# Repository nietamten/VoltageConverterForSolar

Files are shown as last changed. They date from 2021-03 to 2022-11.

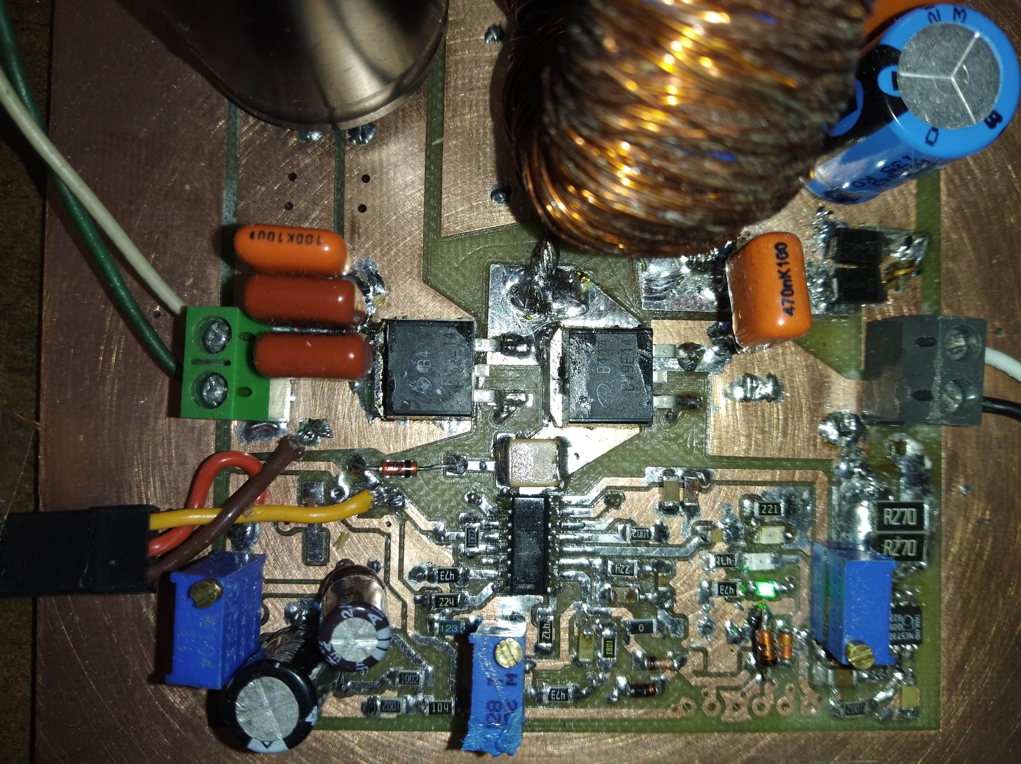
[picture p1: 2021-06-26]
pictures/v2opt.jpg

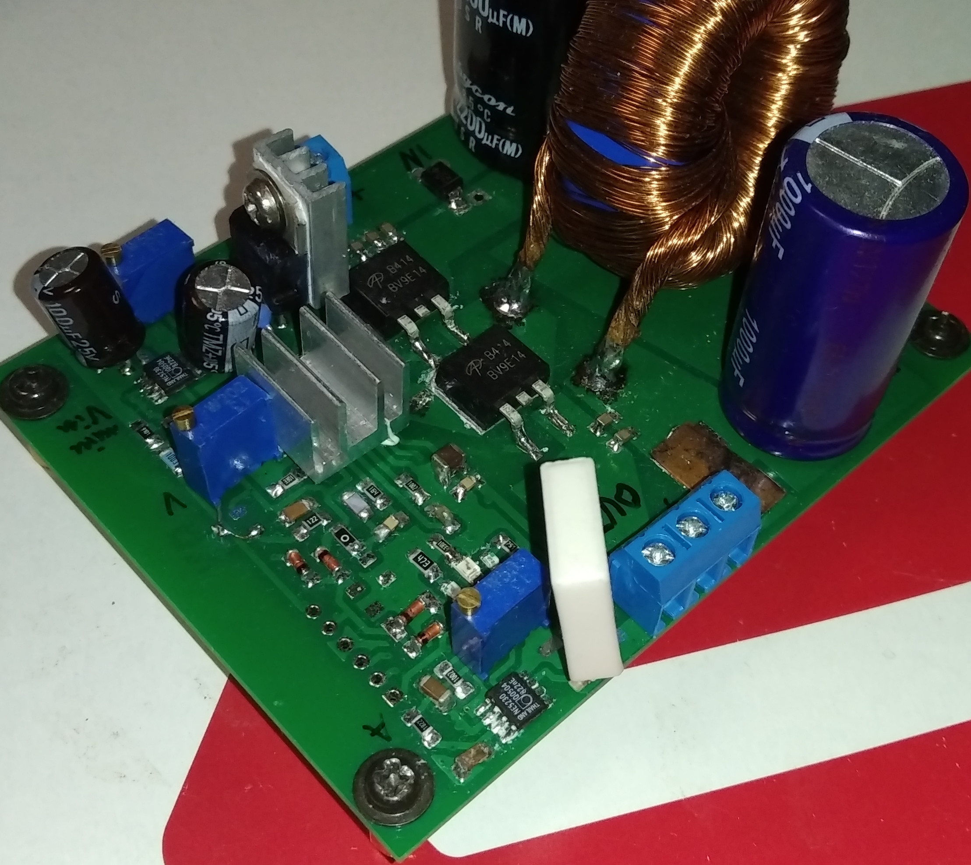
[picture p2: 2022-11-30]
pictures/v3.jpg

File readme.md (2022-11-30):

Kicad project of NCP1034 based buck converter with features useful for solar panels and batteries.

After adjusting compensation network with "Design Spreadsheet for NCP1034" seems to be stable  
If it's not, see troubleshooting section.

There is separate output anode with current limit. It can be used simultaneously with that not limited.
For example battery can be charged with limiting (to not damage it by overcurrent) and some device can use non-limited anode to not distgurb charging.
It is not working ideally (limited output can limit that not limited) but can be helpfull.

Minimum input voltage limit can increase output power by keeping solar panels near maximum power point.
It can be regulated by applying load higher than solar panels power (or when panel are no well illuminated, but not too low illuminated because looses on BD911 regulator becomes dominant and then input voltages lower than at power point gives more power on output) and measuring output power.
Limiting screw should stay in position where power is highest.

NCP1034 have max 80% PWM duty cycle, all power can not pass throw.
Output diodes (D6 and D9) can be replaced with wire, but then converter allows power to flow in reverse direction. When there is no input volatge and on output is battery, battery can charge input capacitors and power on converter and cause losses. 

Assembly notices:
- read NCP1034 datasheet and use xls "design worksheet"
- BD911 gives off a lot of heat, don't ommit radiator, it will be damaged on 15V supply overload
For testing, when short circuits are possible, raplace BD911 based regulator with some other, more failproof
for example LM5008 based converter. Using LM5008 also significantly reduces heat of whole device on light loads.
- do not ommit 3x100nF capacitors on imput, it can cause instability
- current sensing resistor (R13, R16) limits maximum current, use lower resistance when more current is needed to not burn it
- RT pin resistor (R7) was tested between 22k and 47k (90-180kHz), lower resistance (higher frequency) makes more heat on NCP1034, BD911 and AOB414 but seems to improve stability
(I have oversized inductor). Setting too high frequency can very fast cause overheat and damage to NCP1034.
- Touching working converter parts near NCP1034 (for example to check heating) can easily cause damage of NCP1034 and AOB414. Especially overcurrent and soft start circuits.
- do not mount parts without values, for exaple C21

Troubleshooting:
- converter is oscillating fast (there is output power)
  - increase input capacity
  - add low ESR capacitors on input, for example ceramic
  - change frequency (R7)
- converter is oscillating slower (a little or no power on output)
  - decrease output capacity to prevent over current
  - increase current limit (decrease R11), 5k seems to be safe
  - decrease output volage
- converter is oscillating when minimum voltage limit is working
  - try increase C19 or C18
- converter is oscillating when current limiter is working
  - try increase C16 or experiment with C22
- devices near converter stops working (usb mouse)
  - use ferrite filters on input and output
 
Testing  
Device was tested with 4x parallel 75W 91VOC 67VMP solar panels on long wires.
The load was little 24V 300W water heater.
The heater was left on the whole sunny day in room temperature and stay not damagd.
Voltage on output was for some time about 27V so I suspect that it was more than 300W.
AOB414, BD911 and NCP1034 was very hot but below 100C. I'm not sure it can survive that load in higher ambient temperature.
With lighter loads (I'm guessing about 200W) BD911 is hottest. With LM5008 whole converter is only a little warm.

There is not completed automatic maximum power point tracking extension board with some measurments on UART 

V2 tagged version is better for self-made PCB's but have mistake - no resistor at output of  max input voltage limiting opamp.
V3 tagged verion is for PCB's with metalized holes, radiator for transistors can be on second PCB side.

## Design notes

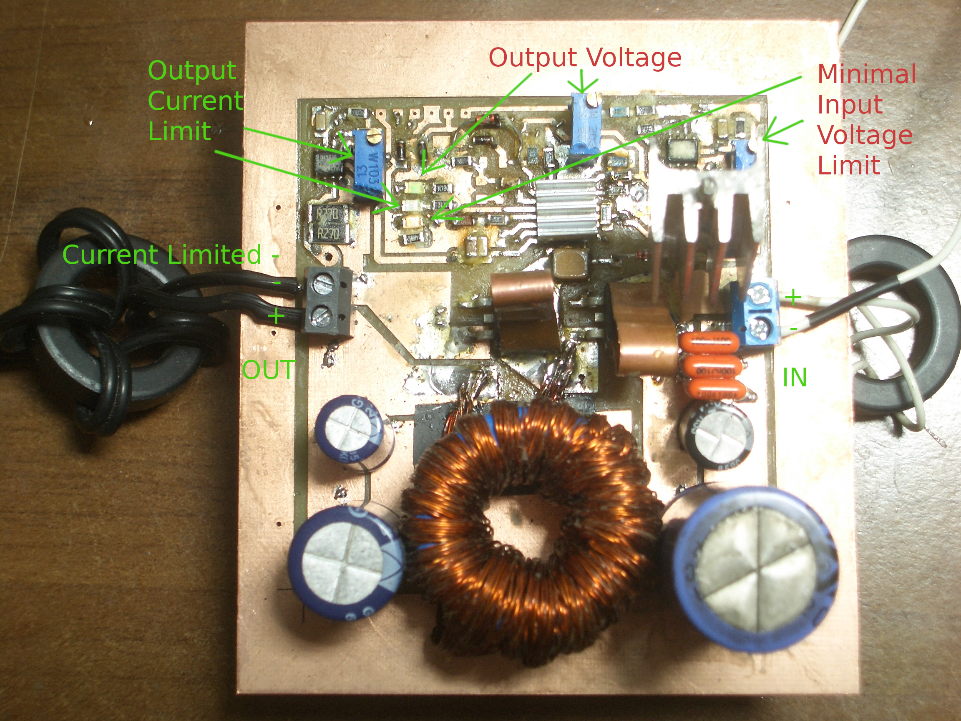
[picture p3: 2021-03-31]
pictures/desc.jpg

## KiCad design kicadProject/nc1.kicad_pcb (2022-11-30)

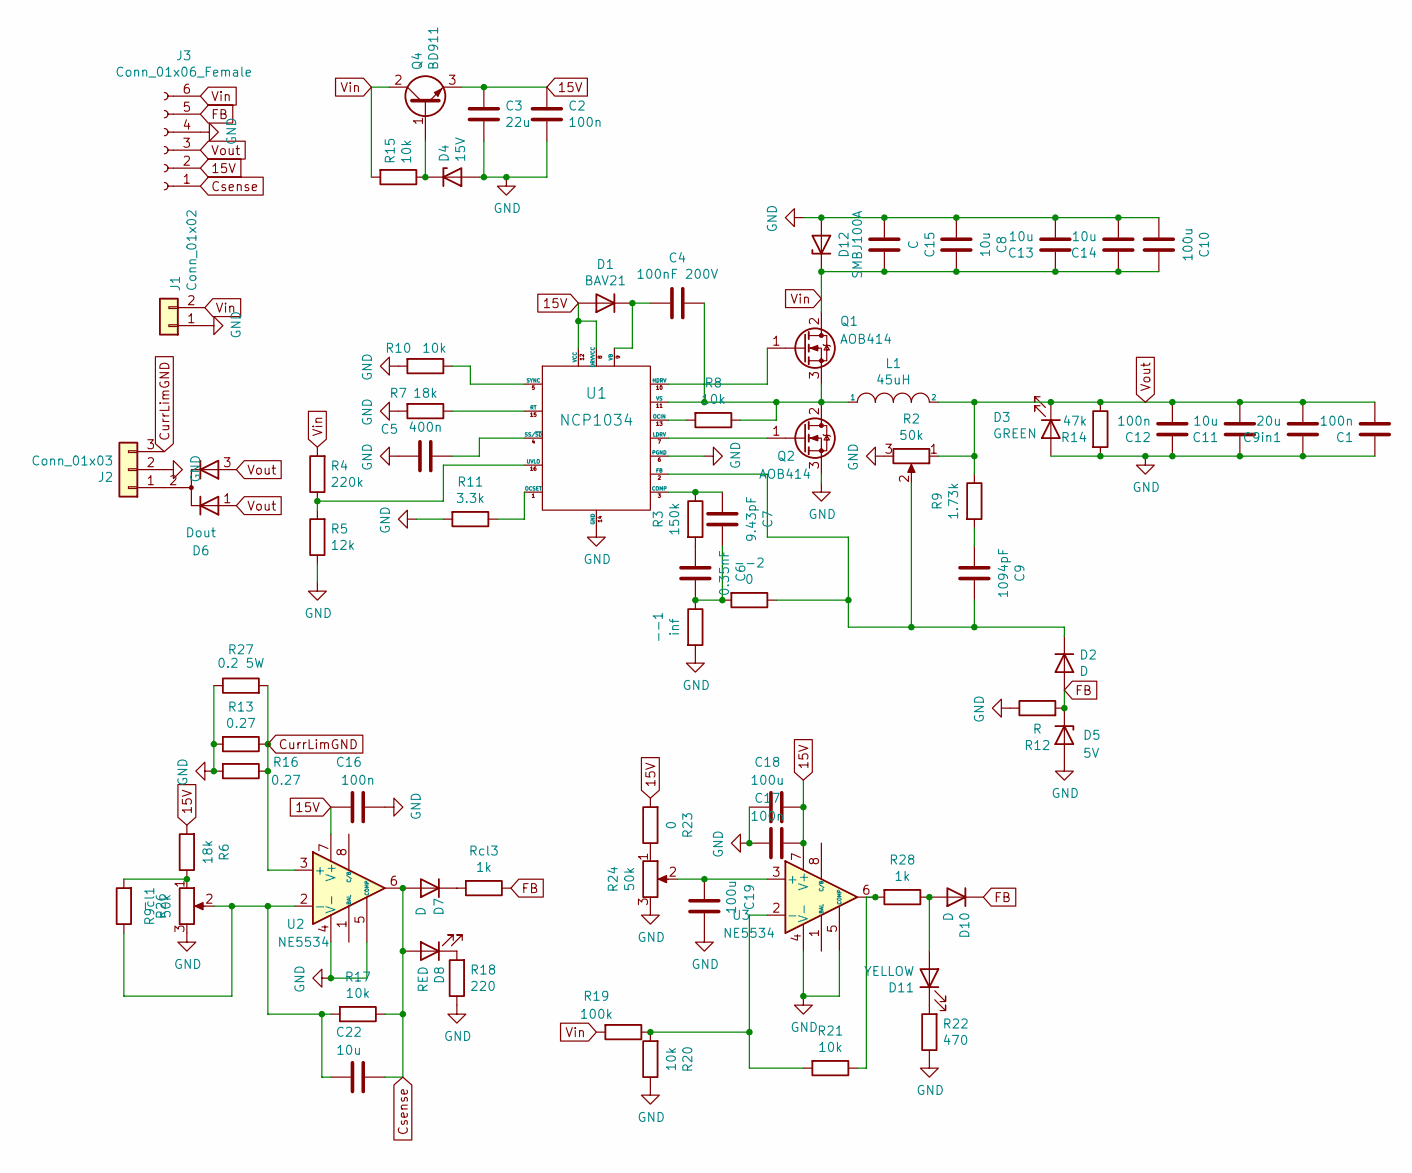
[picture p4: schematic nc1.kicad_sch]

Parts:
--1: inf; R_1206_3216Metric_Pad1.30x1.75mm_HandSolder
--2: 0; R_1206_3216Metric_Pad1.30x1.75mm_HandSolder
C1: 100n; CP_Radial_D18.0mm_P7.50mm
C2: 100n; C_1206_3216Metric
C3: 22u; C_1206_3216Metric
C4: 100nF 200V; C_2220_5650Metric
C5: 400n; C_1206_3216Metric_Pad1.42x1.75mm_HandSolder
C6: 0.35nF; C_1206_3216Metric_Pad1.42x1.75mm_HandSolder
C7: 9.43pF; C_1206_3216Metric_Pad1.42x1.75mm_HandSolder
C8: 10u; C_Rect_L7.0mm_W2.5mm_P5.00mm
C9: 1094pF; C_1206_3216Metric_Pad1.33x1.80mm_HandSolder
C9in1: 20u; C_Rect_L7.0mm_W2.5mm_P5.00mm
C10: 100u; C_Rect_L7.0mm_W2.5mm_P5.00mm
C11, C13, C14: 10u; CP_Radial_D16.0mm_P7.50mm
C12: 100n; C_Rect_L7.0mm_W2.5mm_P5.00mm
C15: C; C_Rect_L7.0mm_W2.5mm_P5.00mm
C16, C17: 100n; C_1206_3216Metric_Pad1.33x1.80mm_HandSolder
C18, C19: 100u; CP_Radial_D5.0mm_P2.50mm
C22: 10u; C_1206_3216Metric_Pad1.33x1.80mm_HandSolder
D1: BAV21; D_A-405_P10.16mm_Horizontal
D2, D7, D10: D; D_MiniMELF
D3: GREEN; LED_0805_2012Metric_Pad1.15x1.40mm_HandSolder
D4: 15V; D_MELF
D5: 5V; D_MELF
D6: Dout; TO-220-3_Vertical
D8: RED; LED_0805_2012Metric_Pad1.15x1.40mm_HandSolder
D11: YELLOW; LED_0805_2012Metric_Pad1.15x1.40mm_HandSolder
D12: SMBJ100A; D_SMB
J1: Conn_01x02; TerminalBlock_bornier-2_P5.08mm
J2: Conn_01x03; TerminalBlock_bornier-3_P5.08mm
J3: Conn_01x06_Female; PinHeader_1x06_P2.54mm_Vertical
L1: 45uH; L_Axial_L9.5mm_D4.0mm_P15.24mm_Horizontal_Fastron_SMCC
Q1, Q2: AOB414; TO-263-2
Q4: BD911; TO-220-3_Vertical
R2, R9cl1, R24: 50k; Potentiometer_Bourns_3296W_Vertical
R3: 150k; R_1206_3216Metric_Pad1.30x1.75mm_HandSolder
R4: 220k; R_1206_3216Metric_Pad1.30x1.75mm_HandSolder
R5: 12k; R_1206_3216Metric_Pad1.30x1.75mm_HandSolder
R6, R7: 18k; R_1206_3216Metric_Pad1.30x1.75mm_HandSolder
R8, R10, R17, R20, R21: 10k; R_1206_3216Metric_Pad1.30x1.75mm_HandSolder
R9: 1.73k; R_1206_3216Metric_Pad1.30x1.75mm_HandSolder
R11: 3.3k; R_1206_3216Metric_Pad1.30x1.75mm_HandSolder
R12: R; R_1206_3216Metric_Pad1.30x1.75mm_HandSolder
R13, R16: 0.27; R_2010_5025Metric_Pad1.40x2.65mm_HandSolder
R14: 47k; R_1206_3216Metric_Pad1.30x1.75mm_HandSolder
R15: 10k; R_Axial_DIN0207_L6.3mm_D2.5mm_P10.16mm_Horizontal
R18: 220; R_1206_3216Metric_Pad1.30x1.75mm_HandSolder
R19: 100k; R_1206_3216Metric_Pad1.30x1.75mm_HandSolder
R22: 470; R_1206_3216Metric_Pad1.30x1.75mm_HandSolder
R23: 0; R_1206_3216Metric_Pad1.30x1.75mm_HandSolder
R26: -; R_1206_3216Metric_Pad1.30x1.75mm_HandSolder
R27: 0.2 5W; R_Radial_Power_L16.1mm_W9.0mm_P7.37mm
R28: 1k; R_1206_3216Metric_Pad1.30x1.75mm_HandSolder
Rcl3: 1k; R_0805_2012Metric
U1: NCP1034; SOIC-16_3.9x9.9mm_P1.27mm
U2, U3: NE5534; SOIC-8_3.9x4.9mm_P1.27mm

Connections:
15V: C2.1, C3.1, C16.1, C17.2, C18.2, D1.2 (A), J3.2, Q4.3 (E), R6.2, R23.2, U1.8 (DRVVCC), U1.12 (VCC), U2.7 (V+), U3.7 (V+)
Csense: C22.2, D7.2 (A), D8.2 (A), J3.1, R17.1, U2.6
CurrLimGND: J2.3, R13.1, R16.1, R27.2, U2.3 (+)
FB: D2.2 (A), D5.1 (K), D10.1 (K), J3.5, R12.2, Rcl3.1
GND: --1.2, C1.2, C2.2, C3.2, C5.2, C8.2, C9in1.2, C10.2, C11.2, C12.2, C13.1, C14.1, C15.2, C16.2, C17.1, C18.1, C19.2, D3.2 (A), D4.2 (A), D5.2 (A), D12.2 (A), J1.1, J2.2, J3.4, Q2.3 (S), R2.3, R5.1, R7.2, R9cl1.3, R10.2, R11.2, R12.1, R13.2, R14.2, R16.2, R18.1, R20.1, R22.1, R24.3, R27.1, U1.6 (PGND), U1.14 (GND), U2.4 (V-), U2.5 (COMP), U3.4 (V-), U3.5 (COMP)
unnamed: --1.1, --2.2, C6.1, C7.1
unnamed: --2.1, C9.1, D2.1 (K), R2.2, U1.2 (FB)
unnamed: C4.1, L1.1, Q1.3 (S), Q2.2 (D), R8.1, U1.11 (VS)
unnamed: C4.2, D1.1 (K), U1.9 (VB)
unnamed: C5.1, U1.4 (SS/~SD)
unnamed: C6.2, R3.2
unnamed: C7.2, R3.1, U1.3 (COMP)
unnamed: C9.2, R9.2
unnamed: C19.1, R24.2, U3.3 (+)
unnamed: C22.1, R9cl1.2, R17.2, R26.1, U2.2 (-)
unnamed: D4.1 (K), Q4.1 (B), R15.1
unnamed: D7.1 (K), Rcl3.2
unnamed: D8.1 (K), R18.2
unnamed: D10.2 (A), D11.2 (A), R28.1
unnamed: D6.2 (A), J2.1
unnamed: Q1.1 (G), U1.10 (HDRV)
unnamed: Q2.1 (G), U1.7 (LDRV)
unnamed: R4.1, R5.2, U1.16 (UVLO)
unnamed: R7.1, U1.15 (RT)
unnamed: R8.2, U1.13 (OCIN)
unnamed: R11.1, U1.1 (OCSET)
unnamed: R19.1, R20.2, R21.2, U3.2 (-)
unnamed: R21.1, R28.2, U3.6
unnamed: D11.1 (K), R22.2
unnamed: R23.1, R24.1
unnamed: R6.1, R9cl1.1, R26.2
unnamed: R10.1, U1.5 (SYNC)
Vin: C8.1, C10.1, C13.2, C14.2, C15.1, D12.1 (K), J1.2, J3.6, Q1.2 (D), Q4.2 (C), R4.2, R15.2, R19.2
Vout: C1.1, C9in1.1, C11.1, C12.1, D3.1 (K), D6.1 (K), D6.3 (K), J3.3, L1.2, R2.1, R9.1, R14.1

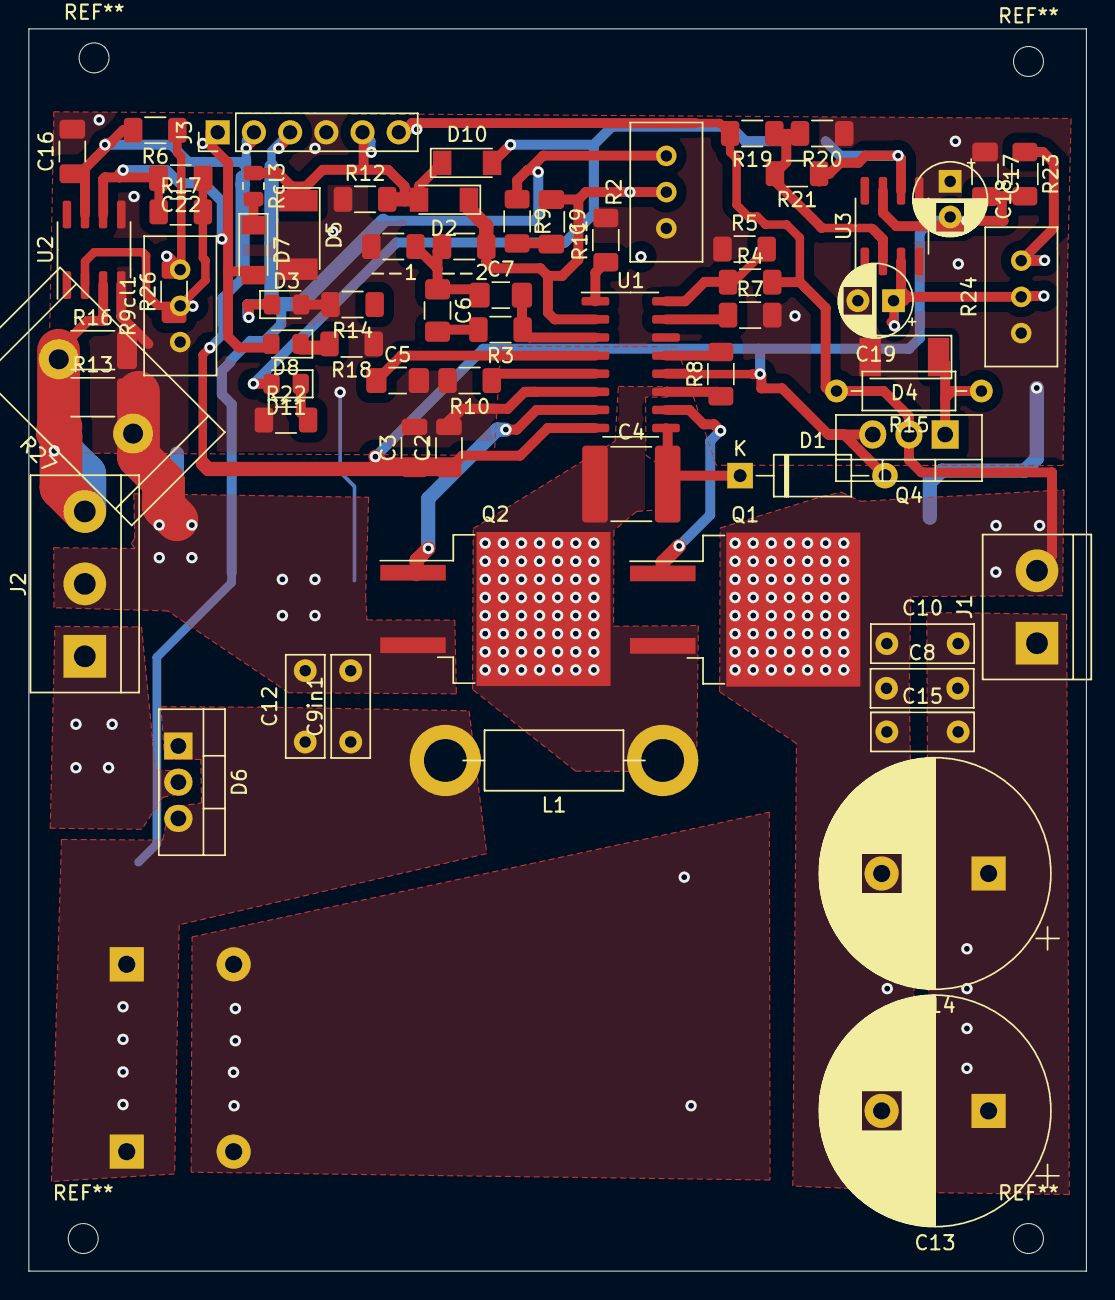
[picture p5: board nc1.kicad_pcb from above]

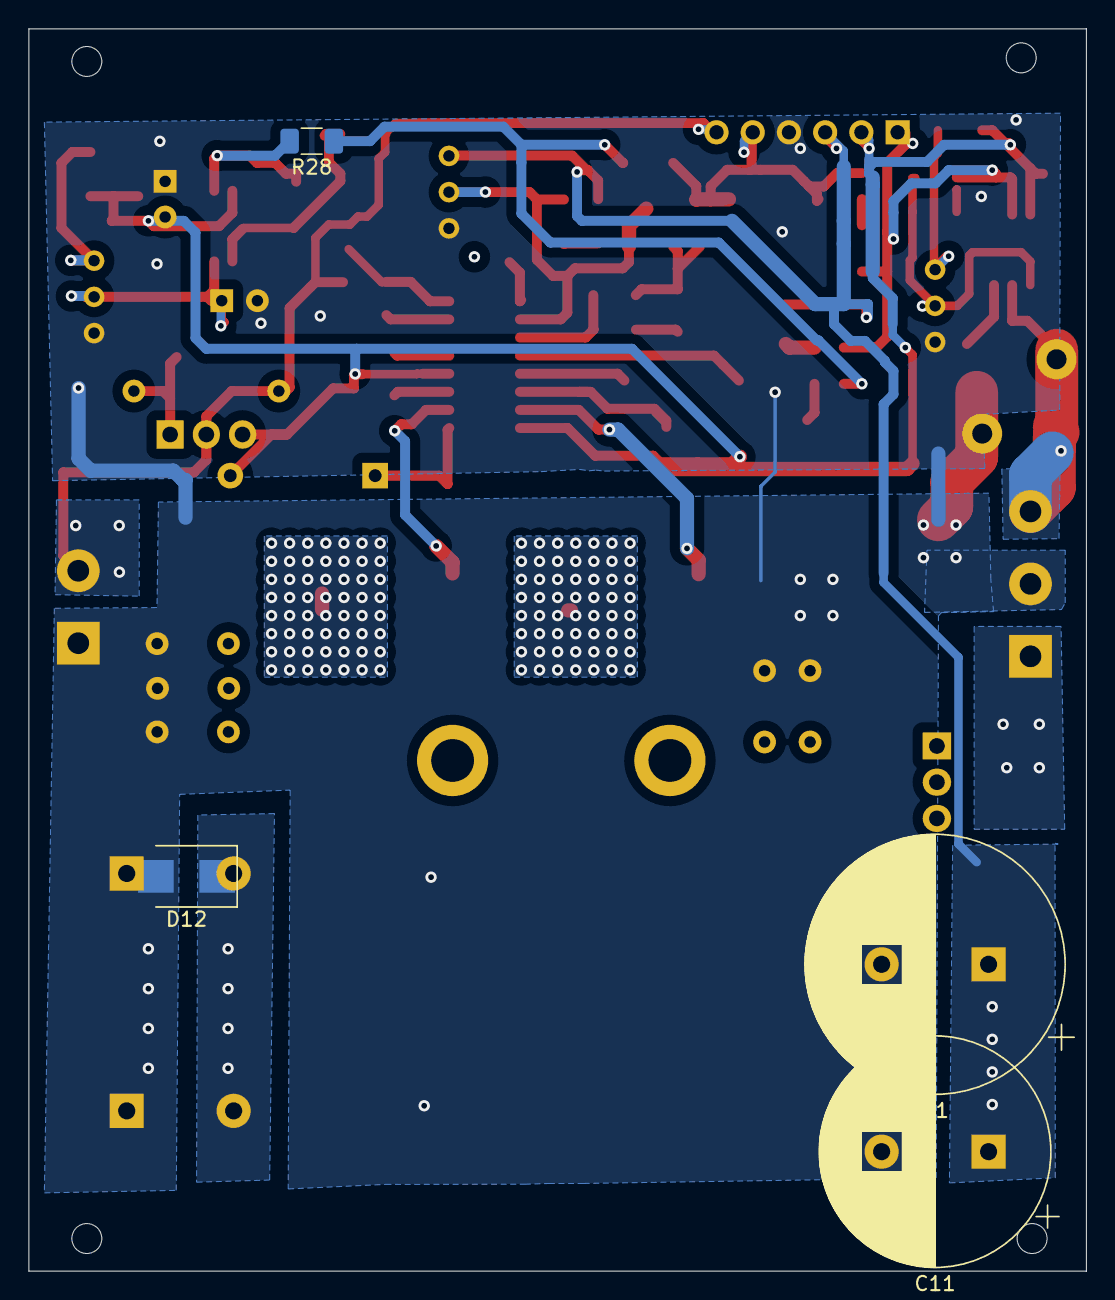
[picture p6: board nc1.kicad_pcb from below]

Board: 2 copper layers, 74.2 x 87.1 mm, 72 parts (4 on the bottom side), 34 nets.

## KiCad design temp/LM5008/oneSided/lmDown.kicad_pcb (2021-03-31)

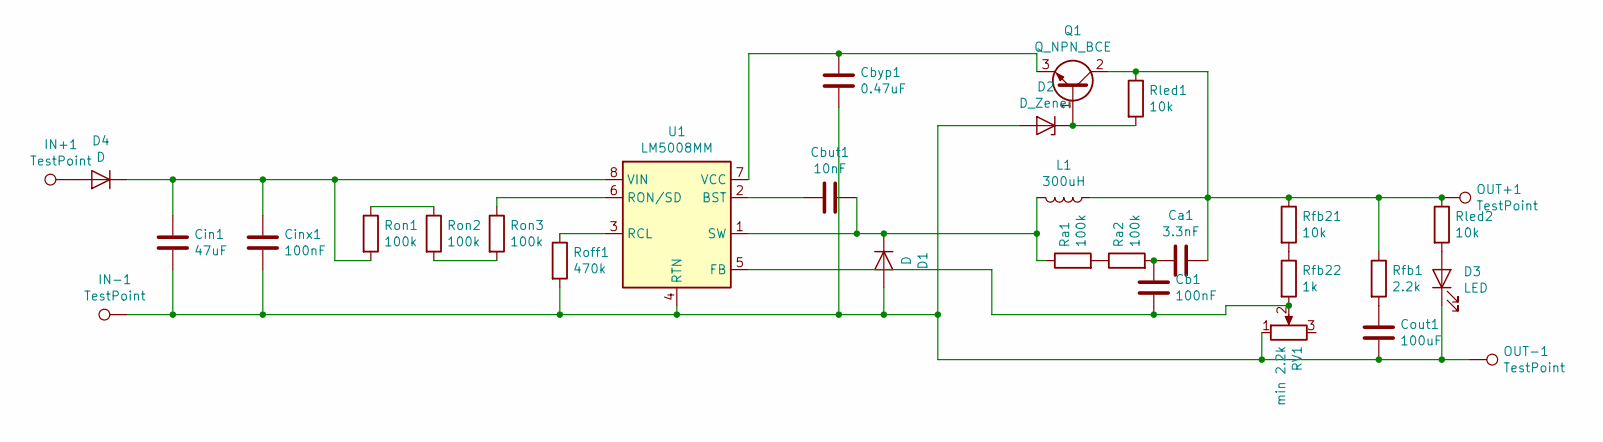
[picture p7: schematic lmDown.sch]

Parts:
Ca1: 3.3nF; C_1206_3216Metric_Pad1.42x1.75mm_HandSolder
Cb1: 100nF; C_1206_3216Metric_Pad1.42x1.75mm_HandSolder
Cbut1: 10nF; C_Disc_D7.5mm_W5.0mm_P5.00mm
Cbyp1: 0.47uF; C_0805_2012Metric_Pad1.15x1.40mm_HandSolder
Cin1: 47uF; CP_Radial_D8.0mm_P3.80mm
Cinx1: 100nF; C_Rect_L7.2mm_W3.5mm_P5.00mm_FKS2_FKP2_MKS2_MKP2
Cout1: 100uF; CP_Radial_D10.0mm_P5.00mm
D1: D; D_DO-15_P10.16mm_Horizontal
D2: D_Zener; D_1206_3216Metric
D3: LED; LED_0805_2012Metric
D4: D; D_A-405_P10.16mm_Horizontal
IN+1: TestPoint; TestPoint_Loop_D2.50mm_Drill1.85mm
IN-1: TestPoint; TestPoint_Loop_D2.50mm_Drill1.85mm
L1: 300uH; L_Radial_D10.0mm_P5.00mm_Fastron_07P
OUT+1: TestPoint; TestPoint_Loop_D2.50mm_Drill1.85mm
OUT-1: TestPoint; TestPoint_Loop_D2.50mm_Drill1.85mm
Q1: Q_NPN_BCE; TO-92L_Inline_Wide
RV1: min 2.2k; Potentiometer_Runtron_RM-065_Vertical
Ra1, Ra2: 100k; R_1206_3216Metric_Pad1.42x1.75mm_HandSolder
Rfb1: 2.2k; R_1206_3216Metric_Pad1.42x1.75mm_HandSolder
Rfb21: 10k; R_1206_3216Metric_Pad1.42x1.75mm_HandSolder
Rfb22: 1k; R_1206_3216Metric_Pad1.42x1.75mm_HandSolder
Rled1, Rled2: 10k; R_1206_3216Metric_Pad1.42x1.75mm_HandSolder
Roff1: 470k; R_1206_3216Metric_Pad1.42x1.75mm_HandSolder
Ron1, Ron2, Ron3: 100k; R_1206_3216Metric_Pad1.42x1.75mm_HandSolder
U1: LM5008MM; MSOP-8_3x3mm_P0.65mm

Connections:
unnamed: Ca1.1, L1.1, OUT+1.1, Q1.2 (C), Rfb1.1, Rfb21.1, Rled1.1, Rled2.1
unnamed: Ca1.2, Cb1.1, Ra2.2
unnamed: Cb1.2, RV1.2, Rfb22.2, U1.5 (FB)
unnamed: Cbut1.1, D1.1 (K), L1.2, Ra1.1, U1.1 (SW)
unnamed: Cbut1.2, U1.2 (BST)
unnamed: Cbyp1.1, Q1.3 (E), U1.7 (VCC)
unnamed: Cbyp1.2, Cin1.2, Cinx1.2, Cout1.2, D1.2 (A), D2.2 (A), D3.1 (K), IN-1.1, OUT-1.1, RV1.1, Roff1.2, U1.4 (RTN)
unnamed: Cin1.1, Cinx1.1, D4.1 (K), Ron1.2, U1.8 (VIN)
unnamed: Cout1.1, Rfb1.2
unnamed: D2.1 (K), Q1.1 (B), Rled1.2
unnamed: D3.2 (A), Rled2.2
unnamed: D4.2 (A), IN+1.1
unnamed: Ra1.2, Ra2.1
unnamed: Rfb21.2, Rfb22.1
unnamed: Roff1.1, U1.3 (RCL)
unnamed 16: Ron1.1, Ron2.1; also elsewhere on the board
unnamed 17: Ron2.2, Ron3.2; also elsewhere on the board
unnamed: Ron3.1, U1.6 (RON/SD)

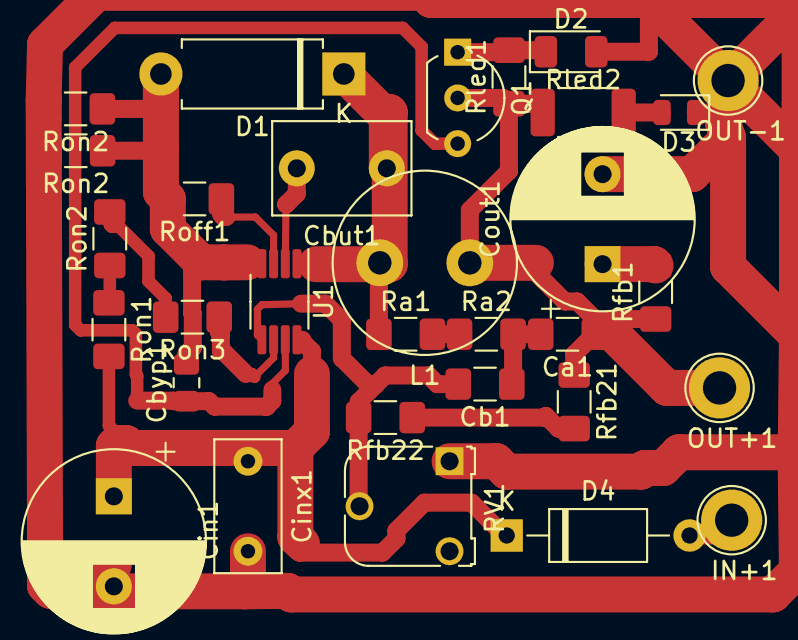
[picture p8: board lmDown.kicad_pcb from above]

Board: 2 copper layers, 31 parts (0 on the bottom side), 18 nets.

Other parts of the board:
Ron2#2, Ron2#3: 100k; R_1206_3216Metric_Pad1.42x1.75mm_HandSolder

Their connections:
unnamed 16: Ron2#2.1, Ron2#3.1; also elsewhere on the board
unnamed 17: Ron2#2.2, Ron2#3.2; also elsewhere on the board

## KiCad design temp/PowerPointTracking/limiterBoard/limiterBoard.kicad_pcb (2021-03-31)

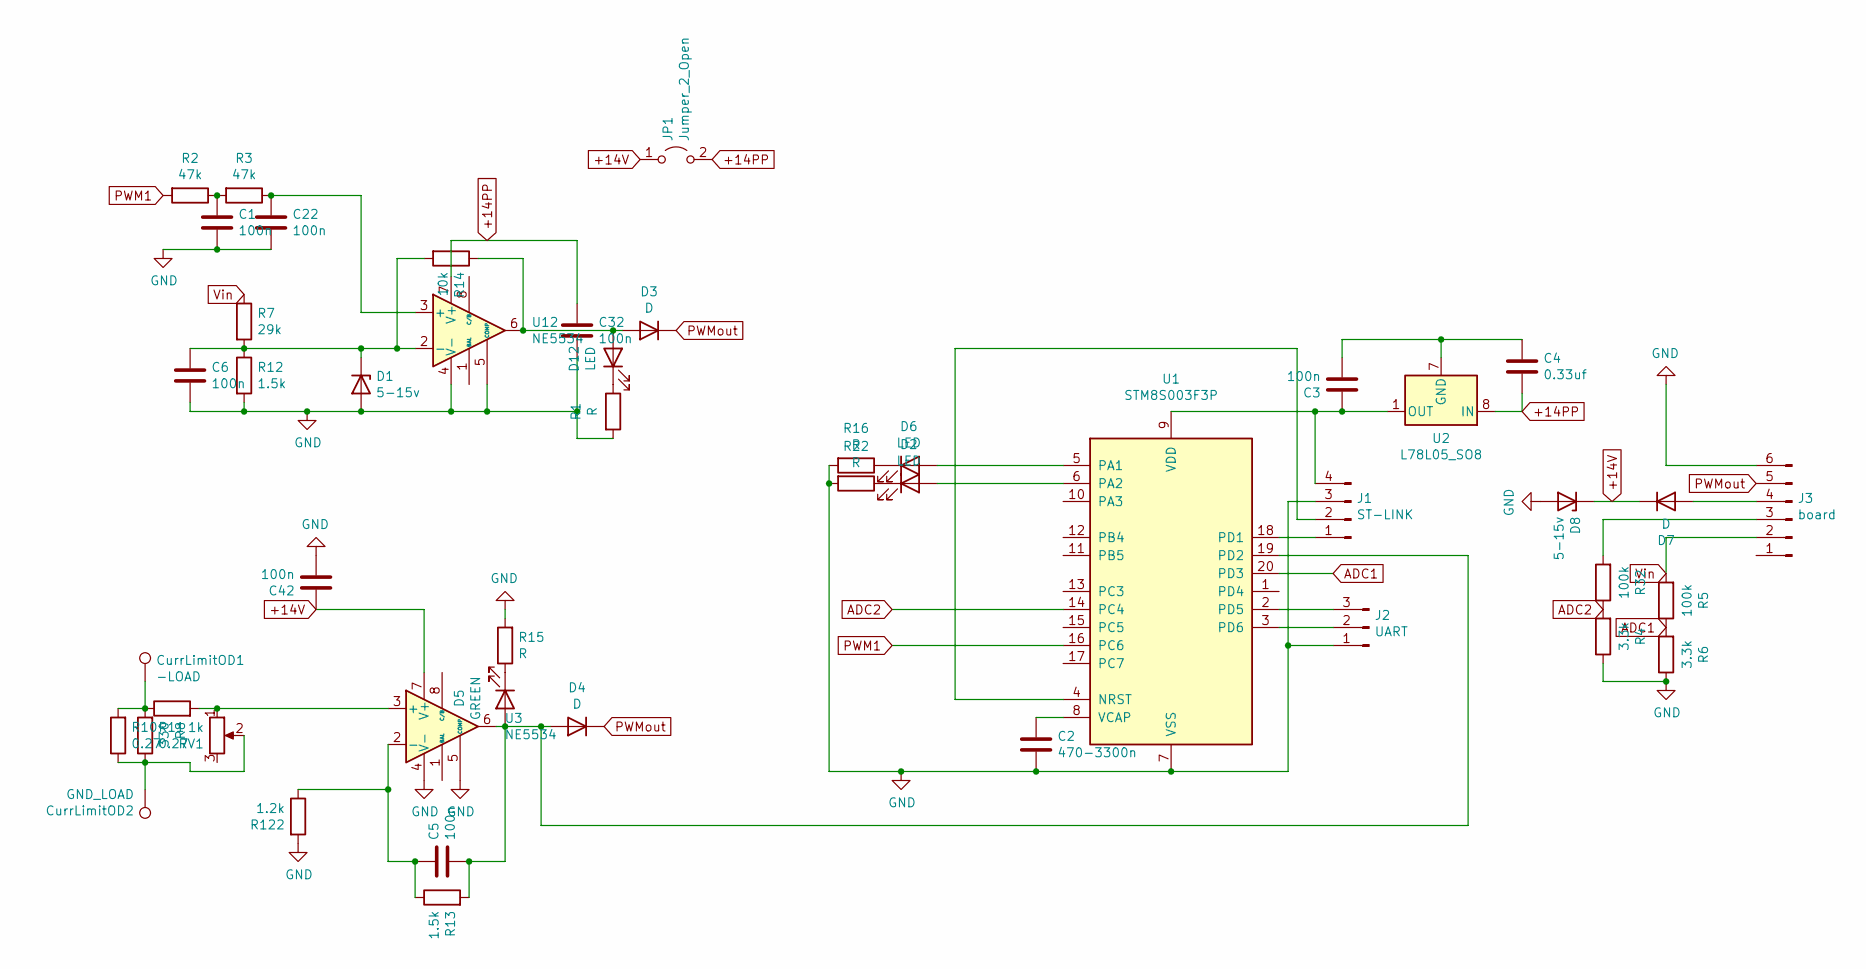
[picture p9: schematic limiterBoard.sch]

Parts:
C1, C3, C5, C6, C22, C32, C42: 100n; C_1206_3216Metric
C2: 470-3300n; C_1206_3216Metric
C4: 0.33uf; C_1206_3216Metric
CurrLimitOD1: -LOAD; SolderWire-0.1sqmm_1x01_D0.4mm_OD1mm
CurrLimitOD2: GND_LOAD; SolderWire-0.1sqmm_1x01_D0.4mm_OD1mm
D1, D8: 5-15v; D_MiniMELF
D2, D6, D12: LED; LED_1206_3216Metric_Pad1.42x1.75mm_HandSolder
D3, D4, D7: D; D_1210_3225Metric
D5: GREEN; LED_1206_3216Metric_Pad1.42x1.75mm_HandSolder
J1: ST-LINK; PinHeader_1x04_P2.54mm_Horizontal
J2: UART; PinHeader_1x03_P2.54mm_Horizontal
J3: board; PinHeader_1x06_P2.54mm_Horizontal
JP1: Jumper_2_Open; PinHeader_1x02_P2.54mm_Vertical
R1, R16, R22: R; R_1206_3216Metric
R2, R3: 47k; R_1206_3216Metric_Pad1.30x1.75mm_HandSolder
R4, R6: 3.3k; R_1206_3216Metric
R5, R32: 100k; R_1206_3216Metric
R7: 29k; R_1206_3216Metric_Pad1.30x1.75mm_HandSolder
R8: 330; R_1206_3216Metric_Pad1.30x1.75mm_HandSolder
R10, R11: 0.27; R_2512_6332Metric
R12, R13: 1.5k; R_1206_3216Metric_Pad1.30x1.75mm_HandSolder
R14: 10k; R_1206_3216Metric_Pad1.30x1.75mm_HandSolder
R15: R; R_1206_3216Metric_Pad1.30x1.75mm_HandSolder
R122: 1.2k; R_1206_3216Metric_Pad1.30x1.75mm_HandSolder
RV1: 1k; Potentiometer_Bourns_3269W_Vertical
U1: STM8S003F3P; TSSOP-20_4.4x6.5mm_P0.65mm
U2: L78L05_SO8; SOIC-8_3.9x4.9mm_P1.27mm
U3, U12: NE5534; SOIC-8_3.9x4.9mm_P1.27mm

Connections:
+14PP: C4.2, C32.1, JP1.2 (B), U2.8 (IN), U12.7 (V+)
+14V: C42.1, D7.1 (K), D8.1 (K), JP1.1 (A), U3.7 (V+)
ADC1: R5.1, R6.2, U1.20 (PD3)
ADC2: R4.2, R32.1, U1.14 (PC4)
GND: C1.2, C2.2, C6.2, C22.2, C32.2, C42.2, D1.2 (A), D8.2 (A), J1.3, J2.1, J3.6, R1.2, R4.1, R6.1, R12.2, R15.2, R16.2, R22.2, R122.2, U1.7 (VSS), U3.4 (V-), U3.5 (COMP), U12.4 (V-), U12.5 (COMP)
unnamed: C1.1, R2.1, R3.2
unnamed: C2.1, U1.8 (VCAP)
unnamed: C3.1, J1.4, U1.9 (VDD), U2.1 (OUT)
unnamed: C3.2, C4.1, U2.2 (GND), U2.3 (GND), U2.6 (GND), U2.7 (GND)
unnamed: C5.1, R13.1, R122.1, U3.2 (-)
unnamed: C5.2, D4.2 (A), D5.2 (A), R13.2, U1.19 (PD2), U3.6
unnamed: C6.1, D1.1 (K), R7.2, R12.1, R14.2, U12.2 (-)
unnamed: C22.1, R3.1, U12.3 (+)
unnamed: CurrLimitOD1.1, R8.1, R10.2, R11.2
unnamed: CurrLimitOD2.1, R10.1, R11.1, RV1.2
unnamed: D2.1 (K), R22.1
unnamed: D2.2 (A), U1.6 (PA2)
unnamed: D5.1 (K), R15.1
unnamed: D6.1 (K), R16.1
unnamed: D6.2 (A), U1.5 (PA1)
unnamed: D7.2 (A), J3.4
unnamed: D12.1 (K), R1.1
unnamed: D3.2 (A), D12.2 (A), R14.1, U12.6
unnamed: J1.1, U1.18 (PD1)
unnamed: J1.2, U1.4 (NRST)
unnamed: J2.2, U1.3 (PD6)
unnamed: J2.3, U1.2 (PD5)
unnamed: J3.3, R32.2
unnamed: R8.2, RV1.1, U3.3 (+)
PWM1: R2.2, U1.16 (PC6)
PWMout: D3.1 (K), D4.1 (K), J3.5
Vin: J3.2, R5.2, R7.1

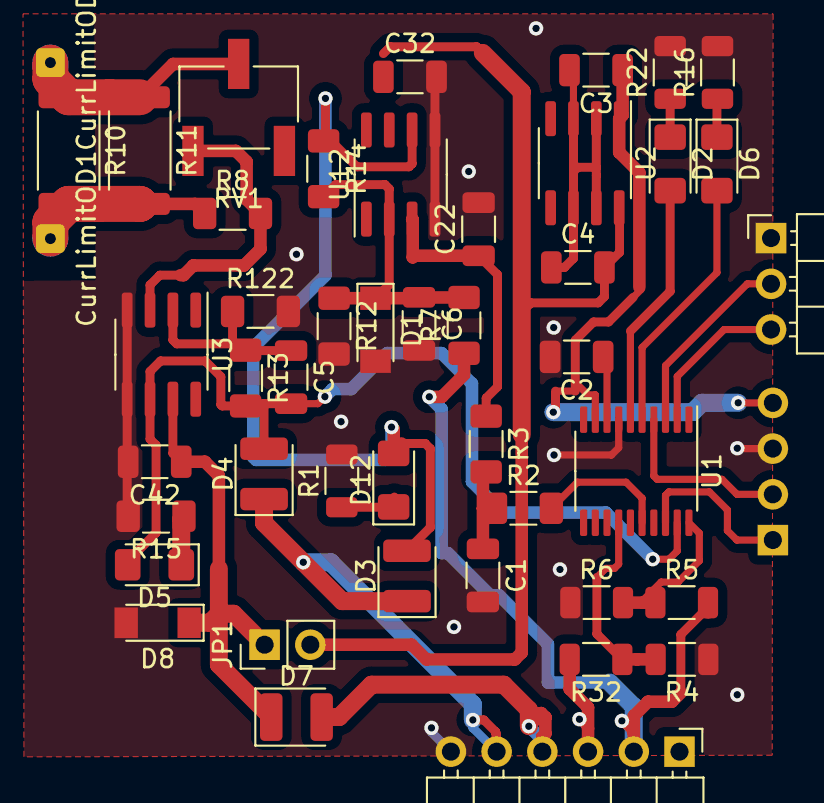
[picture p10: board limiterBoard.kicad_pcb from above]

Board: 2 copper layers, 47 parts (1 on the bottom side), 32 nets.

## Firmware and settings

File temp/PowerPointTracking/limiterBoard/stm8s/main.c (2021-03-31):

#include <stdint.h>
#include <stdio.h>
#include <stm8s.h>
#include <uart.h>
#include <delay.h>


#define TIM1_CCER1_CC1E 1
#define TIM1_CCER1_CC2E 2
#define TIM1_OCMODE_PWM1 0x60
#define TIM1_EGR_UG 1
#define TIM1_BKR_MOE 0x80
#define TIM1_CR1_CEN 1

#define PWM_MAX 6553//55000//65534

#define ADC_VOUT 2
#define ADC_COUT 3
#define ADC_VIN 4

            //#define V_REF 3.3
            //#define V_DIV 0.03194
            //1/(3300/(3300+100000))*(3.3/1024)
            //.1008789048 !!!
            // (wynik z adc to mniej wiecej ilosc woltow * 10)

static void iwdg_enable() {
    /* enable IWDG */
    IWDG_KR = IWDG_KEY_ENABLE;

    /* enable write access */
    IWDG_KR = IWDG_KEY_ACCESS;

    /* prescaler = 64 */
    IWDG_PR |= 4;

    /* timeout = 250ms */
    IWDG_RLR = 0xFA;

    /* reload watchdog counter */
    IWDG_KR = IWDG_KEY_REFRESH;
}

inline void iwdg_refresh() {
    IWDG_KR = IWDG_KEY_REFRESH;
}


   
#define V_REF 3.3
#define V_DIV 0.03194

#define PADC 0
#define PPWM 1

#define PROBES_CNT 32 //32 *4bytes *2 = 256 bytes -> 1/4 RAM   

//[probe_nr][0-ADC, 1-PWM ]
uint32_t probes[PROBES_CNT][2];

void clearTab(){
    for(uint8_t i=0;i<PROBES_CNT;i++){
        probes[i][PADC] = 0;
        probes[i][PPWM] = 0;
    }
}

uint16_t ADC_read() {
    uint8_t adcH, adcL;
    ADC1_CR1 |= (1 << ADC1_CR1_ADON);
    while (!(ADC1_CSR & (1 << ADC1_CSR_EOC)));
    adcL = ADC1_DRL;
    adcH = ADC1_DRH;
    ADC1_CSR &= ~(1 << ADC1_CSR_EOC); // clear EOC flag
    return (adcL | (adcH << 8));
}

uint16_t ADC_readL(uint32_t cnt, uint8_t in) {
    uint64_t sum =0;
    for(uint32_t i=0;i<cnt;i++){
        iwdg_refresh();
        sum += ADC_read();
        //delay_us(10);
    }
    uint16_t avg = sum/cnt;
    
    if (in == 1)
        return (float)(avg)*1.51419;    
    else if (in == 0)
        return (float)(avg)*1.52985;
    //else if (in == 2)        
    //    return (float)(avg)/4;
    
    return avg;
}

void ADC_conf(uint8_t s)
{
    /* power down */
    //ADC1_CR1 &= ~(1 << ADC1_CR1_ADON);

    // right-align ADC
    ADC1_CR2 |= (1 << ADC1_CR2_ALIGN);

    /* configure ADC channel 4 (PD3)  */
    //ADC1_CSR = (1 << s);
    ADC1_CSR = s & 0b00001111;

    /* wake ADC from power down */
    ADC1_CR1 |= (1 << ADC1_CR1_ADON);
}

void put(uint16_t pwm, uint16_t adc, uint16_t adcc){

    if (adcc == 0)
        adcc = 1;

    //printf(" put %u %u \r\n",pwm,adc);
    printf("P %u %u\r\n",pwm,pwm);
    printf("VO %u %u\r\n",adc,adc);  
    printf("CO %u %u\r\n",adcc,adcc);
    uint32_t po = (uint32_t)adc*(uint32_t)adcc;
    printf("PO %lu %lu\r\n",po,po);    

    ADC_conf(ADC_VIN);
    uint16_t ain = ADC_readL(1,1);
    printf("VI %u %u\r\n",ain,ain);      

    //if(pwm == 0)
    //    return;

    uint8_t minI = 0;
    uint32_t minADC = 0;
    
    for(uint8_t i=0;i<PROBES_CNT;i++){
        if(i == 0 || minADC > probes[i][PADC]){
            minI = i;
            minADC = probes[i][PADC];
        }
        if(probes[i][PPWM] == pwm){
            //same pwm -> replace result and finish
            probes[i][PADC] = po;
            return;
        }
    }
    if(po <= minADC)
        return; //worst than all probes -> finish
    probes[minI][PADC] = po;
    probes[minI][PPWM] = pwm;
}

uint16_t get_best_pwm(){
    uint8_t maxI = 0;
    uint32_t maxADC = 0;
    uint16_t maxPWM = 0;
    for(uint8_t i=0;i<PROBES_CNT;i++){
        if(i == 0 || maxADC < probes[i][PADC] || (maxADC == probes[i][PADC] && maxPWM > probes[i][PPWM] ) ){
            maxI = i;
            maxADC = probes[i][PADC];
            maxPWM = probes[i][PPWM];
        }    
    }

    //printf(" best ADC %u PWM %u \r\n",probes[maxI][PADC],probes[maxI][PPWM]);

    return (uint16_t)probes[maxI][PPWM];
}

int putchar(int c) {
    uart_write(c);
    return 0;
}

void PWM_conf()
{
    const uint16_t tim1_prescaler = 0;//16MHz | 65535 -> ~244Hz
    TIM1_PSCRH = (tim1_prescaler >> 8);
    TIM1_PSCRL = (tim1_prescaler & 0xFF);

    const uint16_t tim1_auto_reload = PWM_MAX;//1000;//count to 1000
    TIM1_ARRH = (tim1_auto_reload >> 8);
    TIM1_ARRL = (tim1_auto_reload & 0xFF);

    const uint16_t tim1_compare_reg1 = 0;//initial threshold 1000 = 100% PWM 
    TIM1_CCR1H = (tim1_compare_reg1 >> 8);
    TIM1_CCR1L = (tim1_compare_reg1 & 0xFF);

    // Set up compare channel 1
    TIM1_CCER1 = TIM1_CCER1_CC1E; // Enable compare channel 1 output
    TIM1_CCMR1 = TIM1_OCMODE_PWM1; // Make OC1REF high when counter is less than CCR1 and low when higher

    TIM1_EGR |= TIM1_EGR_UG; // Generate an update event to register new settings
    TIM1_BKR = TIM1_BKR_MOE; // Enable TIM1 output channels
    TIM1_CR1 = TIM1_CR1_CEN; // Enable the counter
}

uint16_t setPWM(uint16_t tim1_compare_reg1){
    if (tim1_compare_reg1>PWM_MAX)
        tim1_compare_reg1 = PWM_MAX;            
    TIM1_CCR1H = (tim1_compare_reg1 >> 8);
    TIM1_CCR1L = (tim1_compare_reg1 & 0xFF);
    return tim1_compare_reg1;
}

void gotoPWM(uint16_t pwm){
    //printf("GOTO PWM: %u\r\n",pwm);
    for(int32_t i=PWM_MAX;i>pwm;i--){
        iwdg_refresh();
        setPWM(i);
        delay_10us(1);
    }
    //printf("GOTO DONE \r\n");
}

uint16_t reset(){

    //led on
    PA_ODR |= (1 << 1); 

    setPWM(PWM_MAX);
    iwdg_refresh();
    delay_ms(10);
    iwdg_refresh();

    uint16_t pwm_ = 0;
    uint16_t adc_ = 0;
    uint16_t adcc_ = 0;

    for(uint16_t i=PWM_MAX;i>PWM_MAX/100;i-=PWM_MAX/100){
        iwdg_refresh();
        //printf("- %u\r\n", i);

        setPWM(i);   
        
        put(pwm_,adc_,adcc_);//to spore opoznienie

        ADC_conf(ADC_VOUT);     
        uint16_t aout = ADC_readL(5000,0);    

        ADC_conf(ADC_COUT);     
        uint16_t cout = ADC_readL(5000,2);  
        if (cout == 0)
            cout = 1;

        pwm_ = i;
        adc_ = aout;
        adcc_ = cout;

    }

    gotoPWM(pwm_);

    //led off
    PA_ODR &= ~(1 << 1); 

    return pwm_;
}

uint16_t lastPwm;
uint32_t lastPower = 4294967295;
uint8_t up = 1;

void main() {
    //16MHz main clock
    CLK_CKDIVR = 0;
    
    clearTab();

    PWM_conf();

    //init LED's
    PA_DDR |= (1 << 2);
    PA_DDR |= (1 << 1);
    PA_CR1 |= (1 << 2);
    PA_CR1 |= (1 << 1);

    uart_init();
    
    uint8_t lowain = 0;
    uint16_t steps_cnt = 0;
    uint32_t probes_cnt = 10000;
    uint8_t goup = 1;    

    iwdg_enable();
    lastPwm = reset();
    while (1) {
    
    //led off
    PA_ODR &= ~(1 << 1);     
      
        iwdg_refresh();

        ADC_conf(ADC_VIN);
        uint16_t ain = ADC_readL(1000,1);
        ADC_conf(ADC_VOUT);
        uint16_t aout = ADC_readL(probes_cnt/2,0);
        ADC_conf(ADC_COUT);
        uint16_t acout = ADC_readL(probes_cnt/2,2);
        if(acout == 0)
            acout = 1;

        uint32_t po = aout*acout;

    //led on
    PA_ODR |= (1 << 1); 

        //if (ain < 690)
        {
            if(steps_cnt++ < 30){

                put(lastPwm,aout,acout);

                if (lastPower != 4294967295)
                {
                    //make decision using only last probe
                    if(po < lastPower)
                        up = !up;

                    uint16_t step = steps_cnt*10;//*40;//*60; //...
                    
                    if (lastPwm < step)
                        up = 1;
                    if (lastPwm > PWM_MAX-step)
                        up = 0;                        

/*
                    if(goup){
                        goup = 0;
                        lastPwm = 
                    }

                    if (ain > 670)
                        goup = 0;
goup | */
                    if(up){
                        lastPwm+=step;
                        PA_ODR |= (1 << 2);
                    }
                    else
                    {
                        if (lastPwm >= step)
                            lastPwm-=step;
                        PA_ODR &= ~(1 << 2);
                    }
                }
                
                lastPwm = setPWM(lastPwm);
                lastPower = po;

                probes_cnt = 100000;  
            }
            else if(steps_cnt++ < 500)
            {
                PA_ODR &= ~(1 << 2);

                put(lastPwm,aout,acout);
                
                lastPwm = get_best_pwm();
                lastPower = po;
                
                lastPwm = setPWM(lastPwm);
                //delay_ms(2);
                probes_cnt = 100000;  
            }
            else
            {
                steps_cnt = 0;
                //lastPwm = 0;
                lastPwm = get_best_pwm();
                lastPower = po;
                lastPwm = setPWM(lastPwm);
                goup = 1;           
            }
        }
        //else{
        //    lastPwm = 0;
        //    setPWM(lastPwm);
        //}
    }
}

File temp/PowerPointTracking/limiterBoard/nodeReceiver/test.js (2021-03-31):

var http = require('http');
var fs = require('fs');

const SerialPort = require('serialport')
const port = new SerialPort('/dev/ttyUSB0', {
  baudRate: 115200
});

var P = [];
var VO = [];
var VI = [];
var CO = [];
var PO = [];

let line = "";
port.on('data', function (data) {
  for (let i = 0; i < data.length; i++) {
    if (data[i] == 13 || data[i] == 10) {
      if (line.length != 0) {
        console.log('Data:', line);

        let lineCp = line;
        line = "";

        let pos = 0;

        pos = lineCp.indexOf(" ");
        if (pos == -1)
          continue;
        let t = lineCp.substring(0, pos);
        lineCp = lineCp.substring(pos + 1);
        pos = lineCp.indexOf(" ");
        if (pos == -1)
          continue;
        let v1 = lineCp.substring(0, pos);
        lineCp = lineCp.substring(pos + 1);
        if (pos == -1)
          continue;
        let v2 = lineCp.substring(0, pos);
        lineCp = lineCp.substring(pos + 1);

        if (v1 == v2) {
          let o = {};
          o.time = new Date();
          o.value = v1;

          if (t == "P")
            P.push(o);
          if (t == "VI")
            VI.push(o);
          if (t == "VO")
            VO.push(o);
          if (t == "CO")
            CO.push(o);
          if (t == "PO")
            PO.push(o);                        
        }


      }
    }
    else {
      line += String.fromCharCode(data[i]);
    }
  }

})

http.createServer(function (req, res) {
  if (req.url == '/data') {
    /*
    let out = [];
    for (let i = 0; i < 10; i++) {
      out[i] = {};
      out[i].value = Math.random();
      out[i].time = new Date();
    }
*/
    let out = {};
    out.P = P;
    out.VI = VI;
    out.VO = VO;
    out.CO = CO;
    out.PO = PO;        

    res.write(JSON.stringify(out));

    P = [];
    VI = [];
    VO = [];
    CO = [];
    PO = [];        

    return res.end();

  } else {
    try {
      res.write(fs.readFileSync(req.url.substring(1)));
      return res.end();
    } catch (e) {
      console.error(e);
      return res.end();
    }

  }
}).listen(8080); 

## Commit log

2021-04-21 more compensatioon
    [nc1.kicad_pcb, nc1.sch]
2021-06-25 stability fixes
    [nc1.kicad_pcb, nc1.sch]
